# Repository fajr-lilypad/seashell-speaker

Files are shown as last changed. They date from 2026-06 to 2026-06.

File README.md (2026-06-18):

# Seashell Speaker!

A bluetooth speaker that automatically plays when tilted, encased in a seashell case!

  

I came up with this idea when I was thinking about how to expand my audio projects. This was created for hackclub's fallout program, and after first creating an mp3 player, I though the next step would be to make something that could use bluetooth, and then I took it to the next level by making it tilt activated! By coincidence, this is my second ocean-related project, lol. The design was inspired by the story we all know about hearing the ocean come from a shell, and partly inspired by the purple magic conch shell from spongebob, lol.



# Cad Screenshots

<table>
   <tr>
      <td>
   
</td>
      <td>
   
      </td>
   </tr>
</table>

<table>
  <tr>
    <td>
    
    </td>
    <td>
    
    </td>
    <td>
      
    </td>
  </tr>
</table>

Cad Notes:
- Okay, so CAD took a WHILE. Creating such an organic shape was difficult, so ended up relying on the revolve, sweep, and coil tools. Since there arent any tutorials online for creating this type of shell in Fusion either, I had to experiment with blender along with borrowing pieces of 3d models online. Once I had a shape i was happy with, I turned it into a case by splitting it in half, adding holes for magnets, and enclosure for the speaker standoffs for the pcb, and holes for the speaker wires.
- The case itself is pretty easy to use, and I'm happy with how it turned out. If I could go back and change anything, I'd definetly check before hand that my case and pcb were compatible. Orginally, I had planned to tuck my pcb away in the lip/opening of the shell. However, that would be pretty mush impossible without making a HUGE shell case, so I had to basically do a whole redesign of the pcb and case.

# PCB Screenshots

<table>
  <tr>
    <td>
    
    </td>
    <td>
    
    </td>
    <td>
      
    </td>
  </tr>
</table>

  PCB Notes:
   - For the PCB, I did have to go thorugh a few versions. I mostly focused on creating super compact board without hindering the esp32's antenna, which wasn't too bad. However, my first designs were too big too fit in the case, so I had to go back to the drawing board, where I decided to make a round pcb that would sit between the top and bottom halves of the shell.
   - This pcb includes a tilt sensor, charging module, switch, esp32, speaker output headers, and more (see bom)

# Schematic Screenshot
 
 

 # Zine !!



 # BOM

 | Item                 | Purpose                       | #        | Cost   | Supplier           | Link                                                                                                                                                                                                                                                                                                                                                                                                                                                                                                                                                                                                                                                                                                                                                                                                                                                                                                                                       |
|----------------------|-------------------------------|----------|--------|--------------------|--------------------------------------------------------------------------------------------------------------------------------------------------------------------------------------------------------------------------------------------------------------------------------------------------------------------------------------------------------------------------------------------------------------------------------------------------------------------------------------------------------------------------------------------------------------------------------------------------------------------------------------------------------------------------------------------------------------------------------------------------------------------------------------------------------------------------------------------------------------------------------------------------------------------------------------------|
| SW-520D              | Sensor                        | 1        | $1.13  | Aliexpress         | https://www.aliexpress.us/item/3256805875302445.html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                                                                                                                                                                |
| ESP32                | Microcontroller               | 1        | $3.13  | Aliexpress         | https://www.aliexpress.us/item/3256807714347051.html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           |
| MAX98357A            | Amplifier                     | 1        | $1.78  | Aliexpress         | https://www.aliexpress.us/item/3256805196806369.html?gatewayAdapt=glo2usa4itemAdapt                                                                                                                                                                                                                                                                                                                                                                                                                                                                                                                                                                                                                                                                                                                                                                                                                                                        |
| Small Round Magnets  | Enclosure snaps               | 1        | $0.99  | Aliexpress         | https://www.aliexpress.us/item/3256810289404806.html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                                                                                                                                                   |
| 15mm speaker         | Speaker                       | 1        | $2.17  | Aliexpress         | https://www.aliexpress.us/item/3256809180147331.html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 |
| 3.7V Lithium Battery | Battery                       | 1        | $6.67  | Aliexpress         | https://www.aliexpress.us/item/3256803431098963.html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                                                                                                                                                                                                                                                                             |
| TP4056 Module        | Charging Module               | 1        | $0.82  | Aliexpress         | https://www.aliexpress.us/item/3256808777213556.html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                                                                                                                                                                                         |
| AP2112K              | Voltage Regulator             | 1        | $0.26  | Mouser             | https://www.mouser.com/ProductDetail/Diodes-Incorporated/AP2112K-33TRG1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                                                                                                                                                                                                                                                                                                                                                                                                                                                                                                                                                                                                                                                                                                                                                        |
| 3Pin Slide Switch    | Off/On                        | 1        | $0.90  | Aliexpress         | https://www.aliexpress.us/item/2255801021214741.html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                                                                                                                                                   |
| CH340C               | Serial Chip                   | 1        | $0.94  | Aliexpress         | https://www.aliexpress.us/item/3256809981619787.html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                                                                                                                                                   |
| JST 2 Pin Connector  | battery input, speaker output | 2        | $1.97  | Aliexpress         | https://www.aliexpress.us/item/3256808498055527.html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                                                                                                                                                    |
| USB C Receptacle     | Data Input                    | 1        | $2.02  | Aliexpress         | https://www.aliexpress.us/item/3256809263109556.html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                                                                                                                                                               |
| WS2812B              | LED                           | 2        | $0.20  | Ebee               | https://www.ebee.com/product-detail/worldsemi-ws2812b-v5-w_617514.html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                                                                                                                                                                                                                                                                                                                                                                                                                                                                                                                                                                                                                                                                                |
| 74ACHCT125           | Quad Level Shifter            | 1        | $1.50  | Adafruit           | https://www.adafruit.com/product/1787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                                                                                                                                                                                                                                                                                                                                                                                                                                                                                                                                                                                                                                                                                                                  |
| 10uF C               | Capacitor                     | 3        | $0.40  | Digikey            | https://www.digikey.com/en/products/detail/kyocera-avx/REA0511100M025K/20096372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                                                                                                                                                                                                                                                                                                                                                                                                                                                                                                                                                                                                                                                          |
| 0.1uF C              | Capacitor                     | 5        | $0.32  | Sparkfun           | https://www.sparkfun.com/capacitor-ceramic-0-1uf.html                                                                                                                                                                                                                                                                                                                                                                                                                                                                                                                                                                                                                                                                                                                                                                                                                                                                                      |
| 5.1K R               | Resistor                      | 2        | $0.08  | Electronix Express | https://www.elexp.com/products/130155-1kres-1-watt-5-5-1-k-ohm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                                                                                                                                                                                                                                                                                                                                                                                                                                                                                                                                                                                                                                                               |
| 330 R                | Resistor                      | 1        | $0.15  | Newark             | https://www.newark.com/multicomp-pro/mccfr01sj0331a10/carbon-film-resistor-330-ohm-1w/dp/59K8549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|pcrid||plid||kword||match|e|slid||product|59K8549|pgrid|1231453304461926|ptaid|pla-4580565455222458|&msclkid=0d6d44d2aa3b1af1a3812efec2f401f3                                                                                                                                                                                                                                                                                                                                                                                                                                                                                                                                                                                                                                                     |
| 10K R                | Resistor                      | 3        | $0.19  | Newark             | https://www.newark.com/multicomp-pro/mf12-10k/res-10k-125mw-axial-metal-film/dp/38K5401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                                                                                                                                                                                                                                                                                                                                                                                                                                                                                                                                                                                                                   |
| 100K R               | Resistor                      | 1        | $0.24  | Newark             | https://www.newark.com/ohmite/mox70031003bye/resistor-metal-film-100k-0-25w/dp/49AJ2825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|pcrid||plid||kword||match|e|slid||product|49AJ2825|pgrid|1231453304461926|ptaid|pla-4580565455222458|&msclkid=8346f4e1e0f2133c086d9ecd89969e59                                                                                                                                                                                                                                                                                                                                                                                                                                                                                                                                                                                                                                                             |
| S8050                | Transistor                    | 1        | $0.84  | Aliexpress         | https://www.aliexpress.us/item/3256808228534673.html?src=google&gatewayAdapt=glo2usa                                                                                                                                                                                                                                                                                                                                                                                                                                                                                                                                                                                                                                                                                                                                                                                                                                                       |
| BC847                | Transistor                    | 1        | $0.19  | Mouser             | https://www.mouser.com/ProductDetail/Nexperia/BC847235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                                                                                                                                                                                                                                                                                                                                                                                                                                                                                                                                                                        |
| PCB Order            | PCB                           | 1        | $2.10  | JLCPCB             |                                                                                                                                                                                                                                                                                                                                                                                                                                                                                                                                                                                                                                                                                                                                                                                                                                                                                                                                            |
|                      |                               | Subtotal | $28.99 |                    |                                                                                                                                                                                                                                                                                                                                                                                                                                                                                                                                                                                                                                                                                                                                                                                                                                                                                                                                            |

## Firmware

Unlike my previous audio projects, instead of using a micro sd card storing songs played by a df player, I used bluetooth connection via an esp32 and a BluetoothA2DPSink library I found from user pschatzmann. The code is fairly simple, and checks the tilt sensor in the background periodically, intercepting when a tilt is detected to pause/play audio.

## Build Guide
1. 3D print Case, ensure that standoffs and holes are secure and remove all supports.
2. Collect all electronic parts and perform breadboard testing before soldering onto custom pcb
3. Flash fimrware with new pcb, connect to bluetooth so you see "Bluetooth Speaker Audio Ready to Pair!" message printed.
4. Test out tilt puasing/playing audio
5. Mount fully charged pcb onto built in standoffs in top of case.
6. Place speaker in enclosure, thread wires through holes and plug into headers in pcb.
7. Place magnets in small holes in shell case, snap case shut.

## Notes and Acknowledgements
- Thank you to *hackclub* and the *fallout* team for this oppurtunity and for making this project possible!

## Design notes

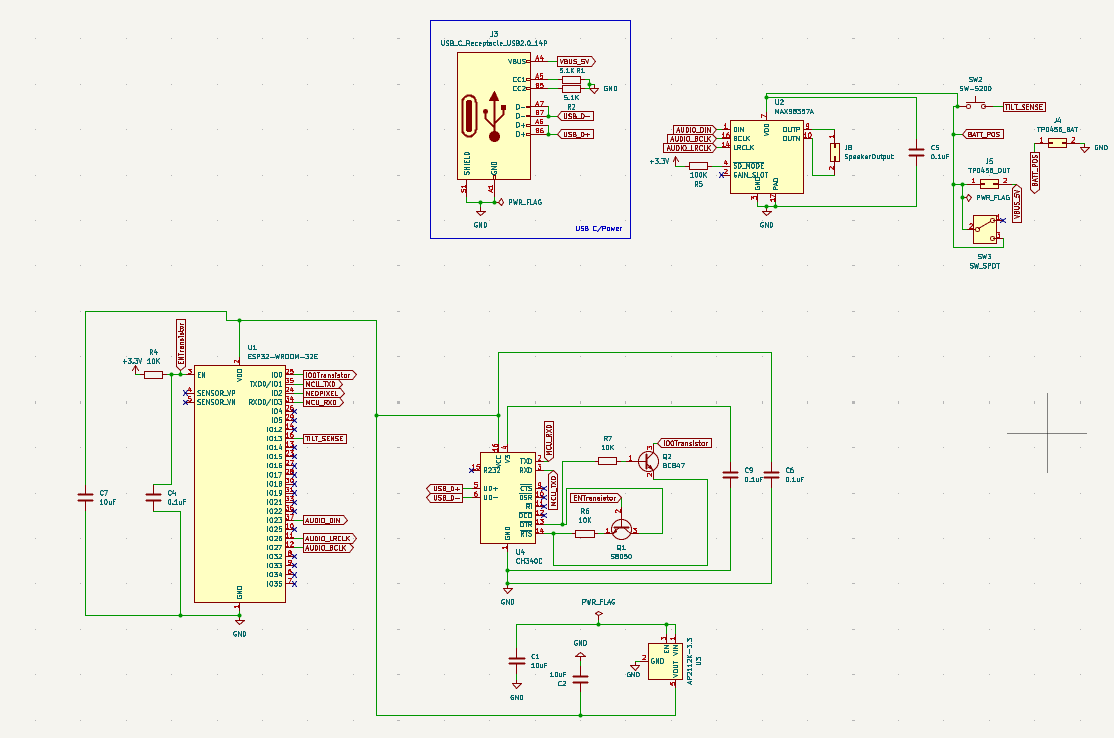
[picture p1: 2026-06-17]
Schematic/Schematic.png

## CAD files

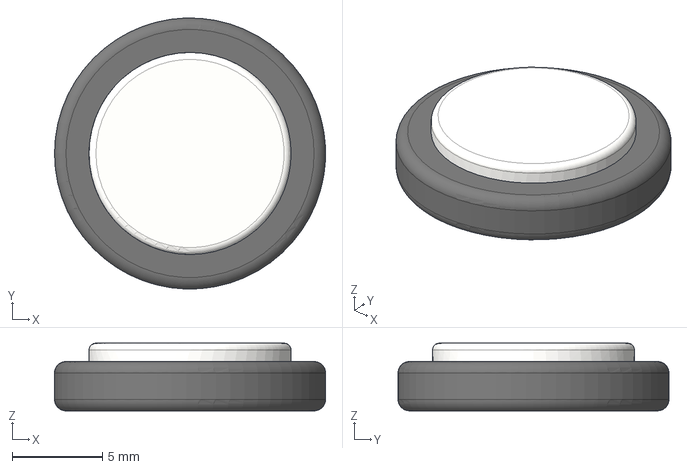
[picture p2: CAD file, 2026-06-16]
CAD/PCB Files/Electronics/15mm speaker.step
15.0 x 15.0 x 3.74 mm

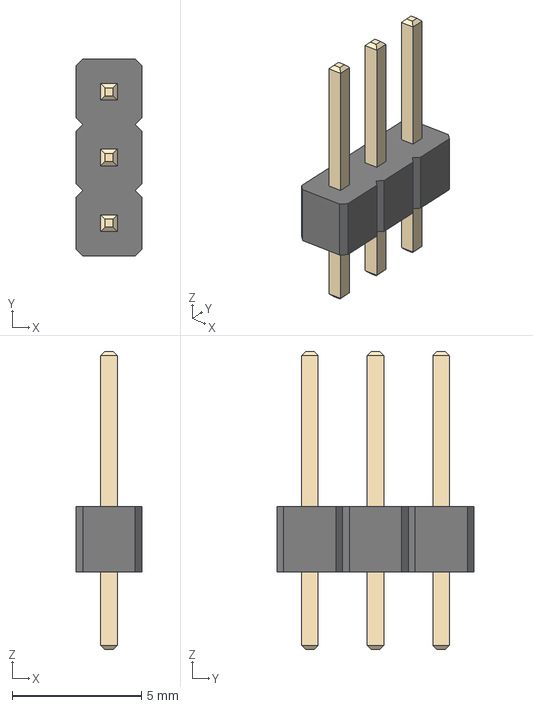
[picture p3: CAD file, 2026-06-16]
CAD/PCB Files/Electronics/PinHeader_1x03_P2.54mm_Vertical (for speaker output).step
2.54 x 7.62 x 11.5 mm

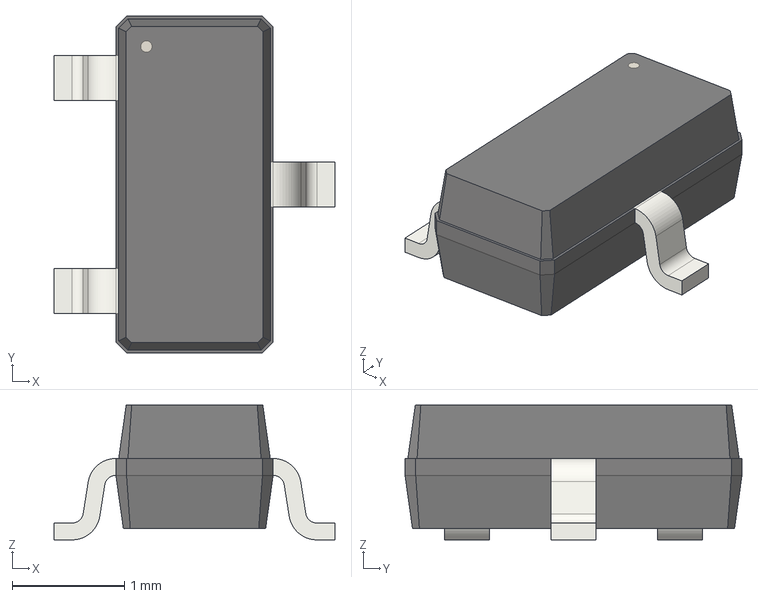
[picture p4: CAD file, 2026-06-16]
CAD/PCB Files/Electronics/SOT-23.step
2.50 x 3.00 x 1.20 mm

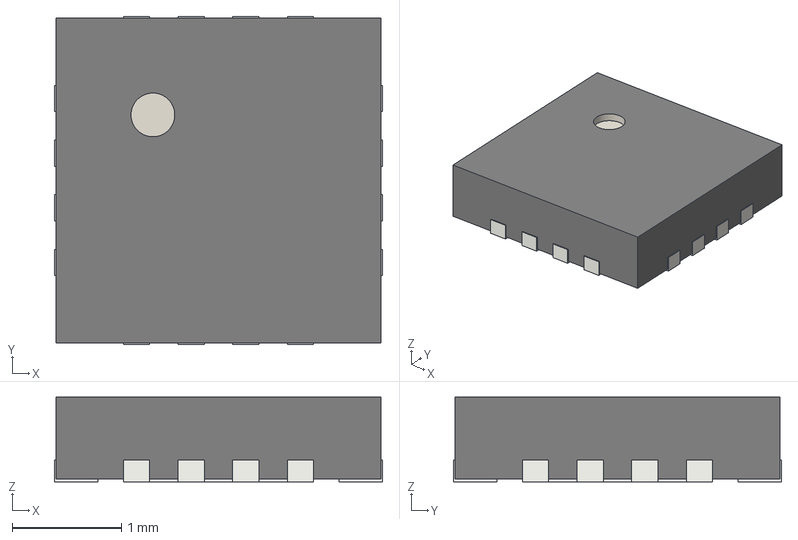
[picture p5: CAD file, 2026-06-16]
CAD/PCB Files/Electronics/TQFN-16-1EP_3x3mm_P0.5mm_EP1.6x1.6mm.step
3.00 x 3.00 x 0.775 mm

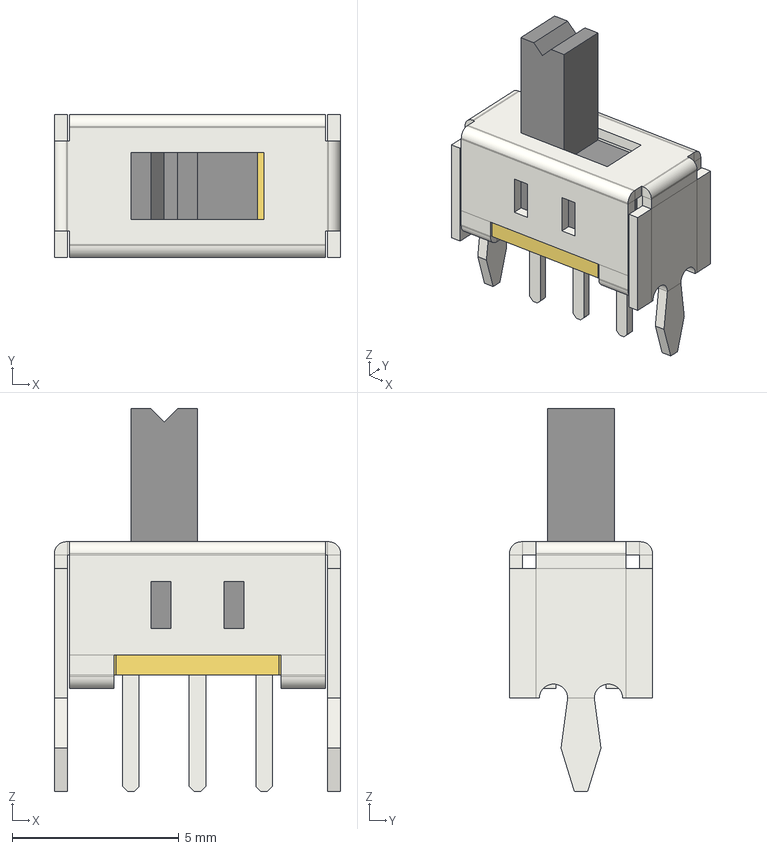
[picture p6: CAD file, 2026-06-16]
CAD/PCB Files/Electronics/SW_Slide_SPDT_Straight_CK_OS102011MS2Q.step
8.60 x 4.30 x 11.5 mm

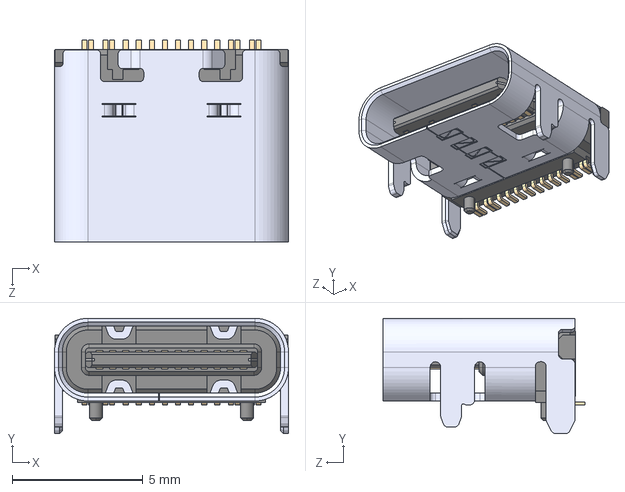
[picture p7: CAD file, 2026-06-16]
CAD/PCB Files/Electronics/USB4105GFA--3DModel-STEP-510211.STEP
8.94 x 4.41 x 7.71 mm

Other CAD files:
CAD/PCB Files/pcb (no components).step
CAD/Full Assembly.f3z

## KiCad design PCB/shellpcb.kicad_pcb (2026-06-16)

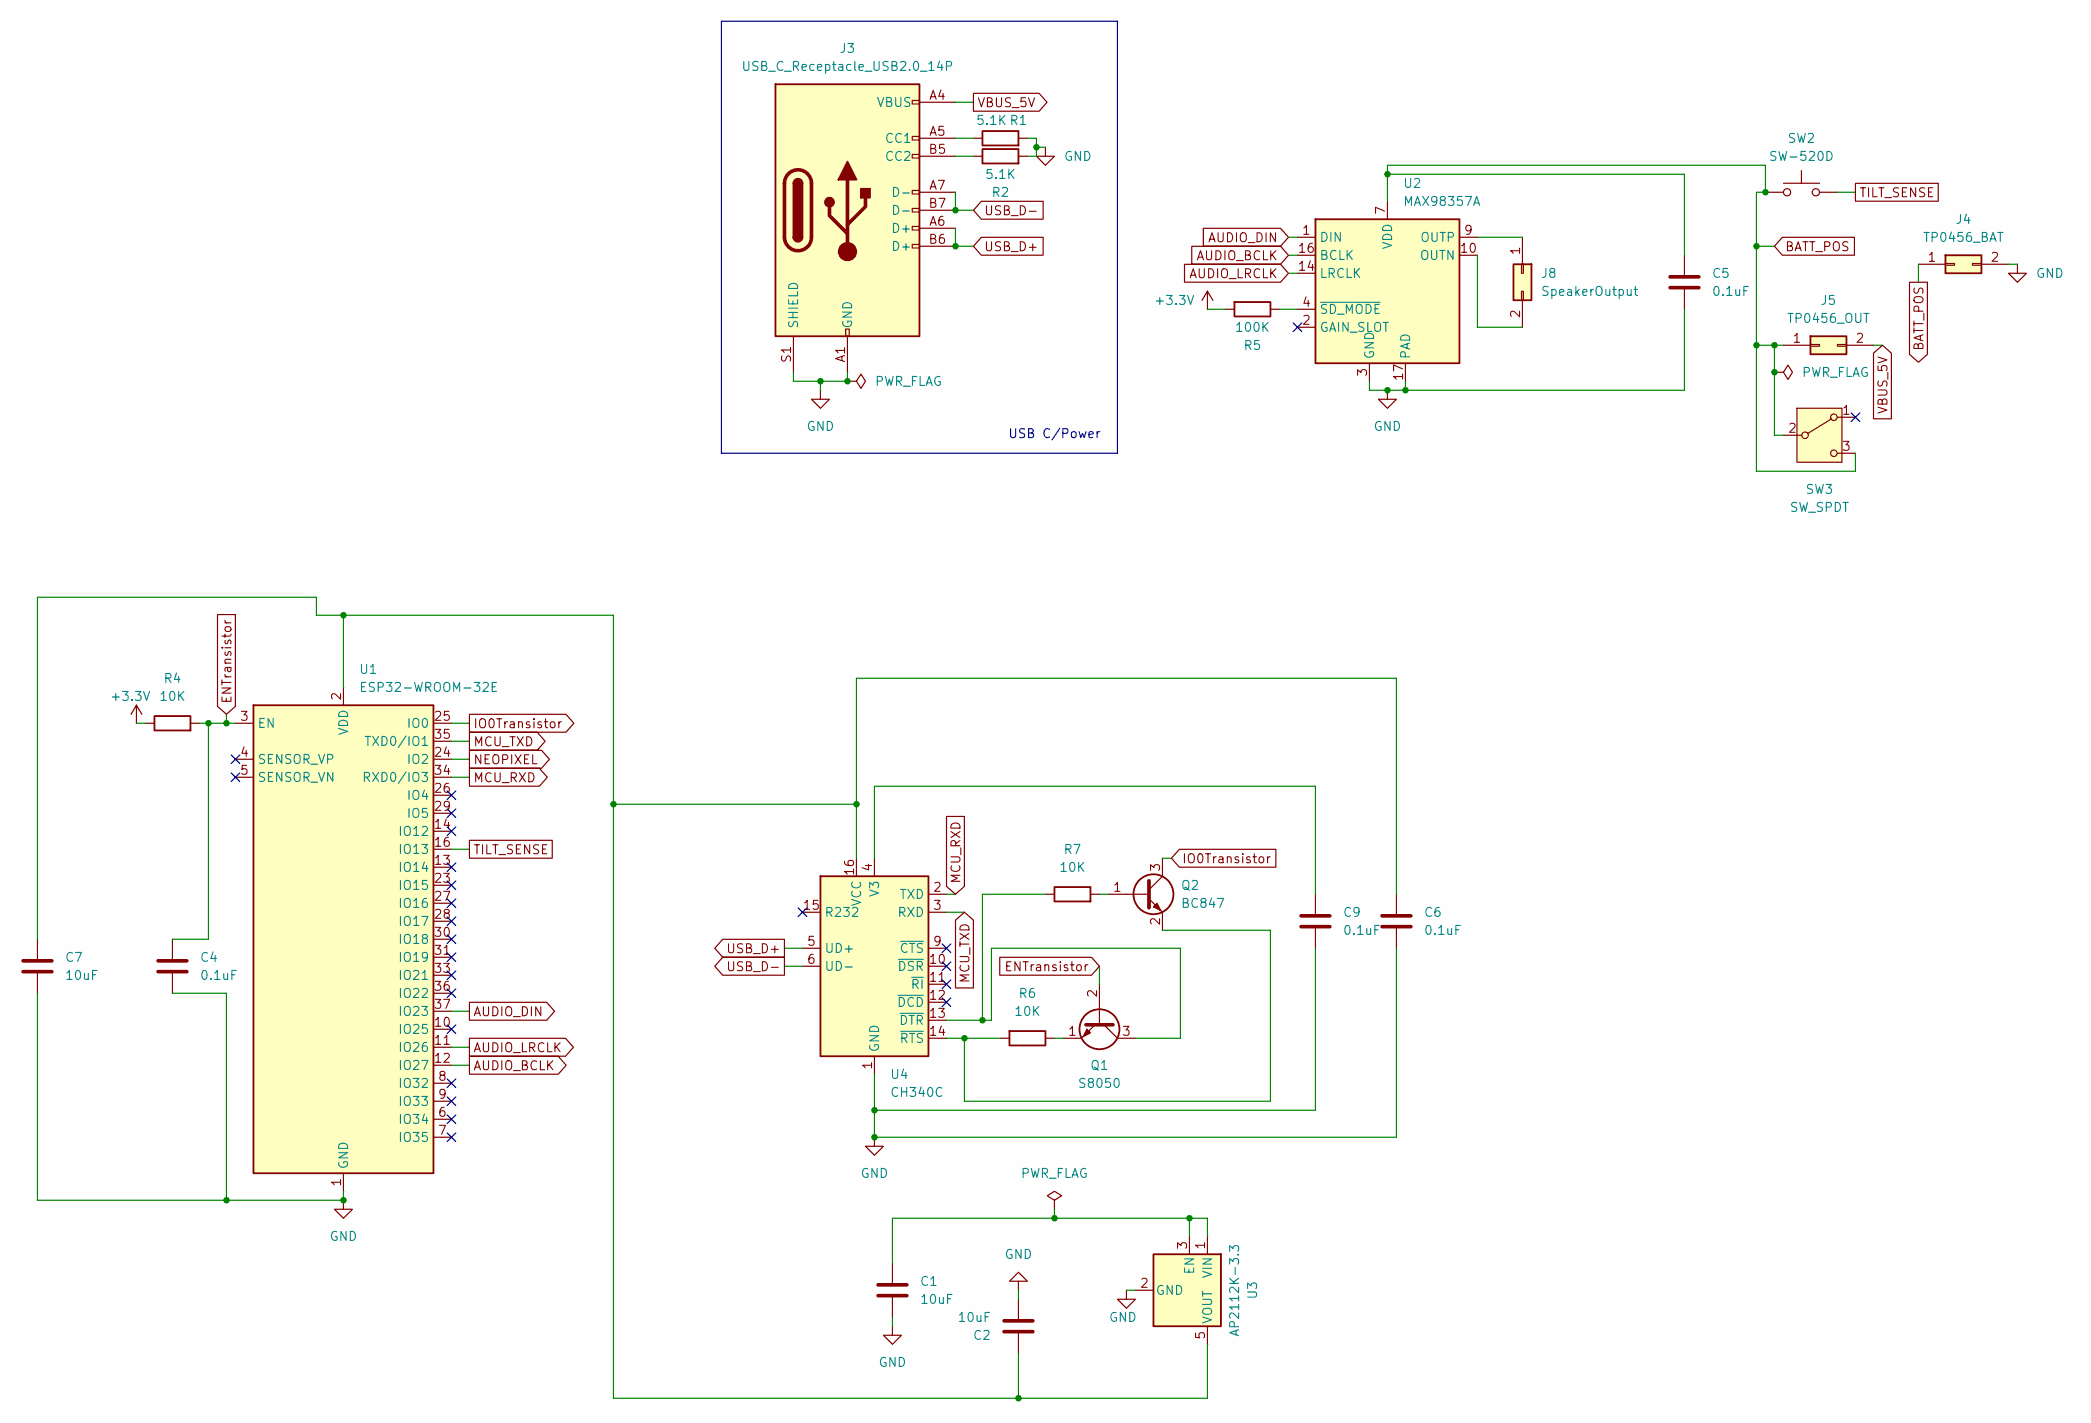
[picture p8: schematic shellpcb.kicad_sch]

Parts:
C1, C2, C7: 10uF; C_0603_1608Metric
C4, C5, C6, C9: 0.1uF; C_0402_1005Metric
J3: USB_C_Receptacle_USB2.0_14P; USB_C_Receptacle_HRO_TYPE-C-31-M-12
J4: TP0456_BAT; Batside
J5: TP0456_OUT; Outside
J8: SpeakerOutput; PinHeader_1x03_P2.54mm_Vertical
Q1: S8050; TO-92_Inline
Q2: BC847; SOT-23
R1, R2: 5.1K; R_0402_1005Metric
R4, R6, R7: 10K; R_0402_1005Metric
R5: 100K; R_0402_1005Metric
SW2: SW-520D; PinHeader_1x02_P2.54mm_Vertical
SW3: SW_SPDT; SW_Slide_SPDT_Straight_CK_OS102011MS2Q
U1: ESP32-WROOM-32E; ESP32-WROOM-32D
U2: MAX98357A; TQFN-16-1EP_3x3mm_P0.5mm_EP1.6x1.6mm
U3: AP2112K-3.3; SOT-23-5
U4: CH340C; SOIC-16_3.9x9.9mm_P1.27mm

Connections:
+3.3V: R4.1, R5.2
AUDIO_BCLK: U1.12 (IO27), U2.16 (BCLK)
AUDIO_DIN: U1.37 (IO23), U2.1 (DIN)
AUDIO_LRCLK: U1.11 (IO26), U2.14 (LRCLK)
BATT_POS: C5.1, J4.1, J5.1, SW2.1, SW3.2 (B), SW3.3 (C), U2.7 (VDD), U2.8 (VDD)
ENTransistor: C4.1, Q1.2 (B), R4.2, U1.3 (EN)
GND: C1.2, C2.1, C4.2, C5.2, C6.2, C7.2, C9.2, J3.A1 (GND), J3.A12 (GND), J3.B1 (GND), J3.B12 (GND), J3.S1 (SHIELD), J4.2, R1.2, R2.2, U1.1 (GND), U1.15 (GND), U1.38 (GND), U1.39 (GND), U2.3 (GND), U2.11 (GND), U2.15 (GND), U2.17 (PAD), U3.2 (GND), U4.1 (GND)
IO0Transistor: Q2.3 (C), U1.25 (IO0)
MCU_RXD: U1.34 (RXD0/IO3), U4.2 (TXD)
MCU_TXD: U1.35 (TXD0/IO1), U4.3 (RXD)
NEOPIXEL: U1.24 (IO2)
unnamed: J3.A5 (CC1), R1.1
unnamed: J3.B5 (CC2), R2.1
unnamed: J8.1, U2.9 (OUTP)
unnamed: J8.2, U2.10 (OUTN)
unnamed: Q1.3 (C), R7.1, U4.13 (~DTR)
unnamed: Q1.1 (E), R6.1
unnamed: Q2.1 (B), R7.2
unnamed: Q2.2 (E), R6.2, U4.14 (~RTS)
unnamed: C2.2, C6.1, C7.1, U1.2 (VDD), U3.5 (VOUT), U4.16 (VCC)
unnamed: R5.1, U2.4 (~SD_MODE)
unnamed: C1.1, U3.1 (VIN), U3.3 (EN)
unnamed: C9.1, U4.4 (V3)
TILT_SENSE: SW2.2, U1.16 (IO13)
USB_D+: J3.A6 (D+), J3.B6 (D+), U4.5 (UD+)
USB_D-: J3.A7 (D-), J3.B7 (D-), U4.6 (UD-)
VBUS_5V: J3.A4 (VBUS), J3.A9 (VBUS), J3.B4 (VBUS), J3.B9 (VBUS), J5.2

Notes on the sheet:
USB C/Power

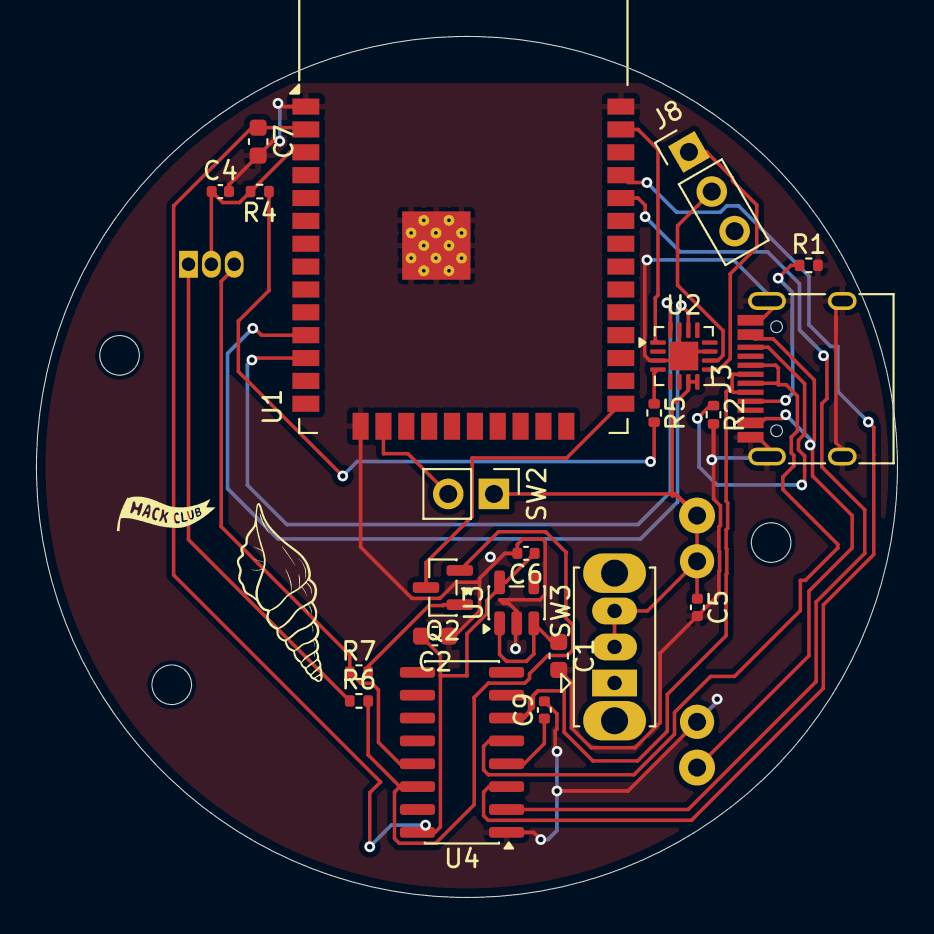
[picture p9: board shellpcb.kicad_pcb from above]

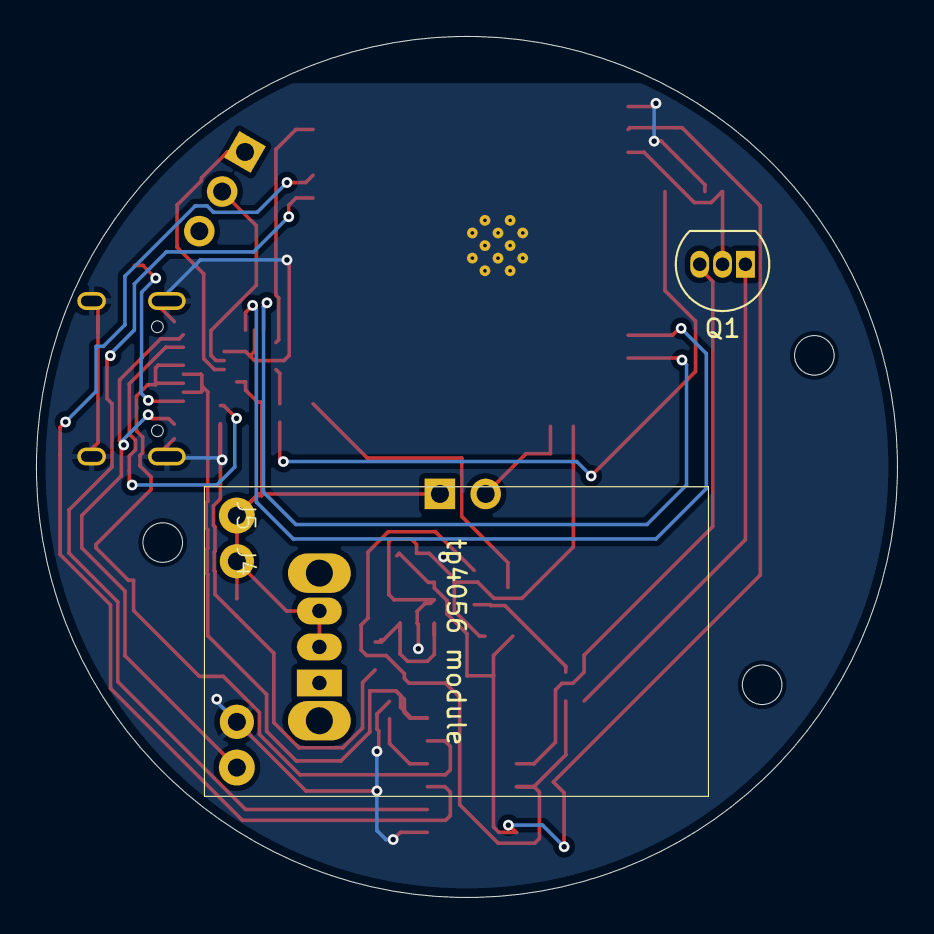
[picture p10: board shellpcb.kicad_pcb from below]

Board: 2 copper layers, 47.8 x 47.8 mm, 25 parts (3 on the bottom side), 26 nets.

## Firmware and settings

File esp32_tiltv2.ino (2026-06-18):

#include "ESP_I2S.h"         // Modern ESP32 Core v3 Audio Driver
#include "BluetoothA2DPSink.h" // Library to turn ESP32 into a BT Speaker

// Define your exact schematic pins for the MAX98357A Amp
#define I2S_BCLK          26  // AUDIO_BCLK on IO26
#define I2S_LRCK          27  // AUDIO_LRCLK on IO27
#define I2S_DOUT          25  // AUDIO_DIN on IO25

#define TILT_SWITCH_PIN   12  // SW2 connected to IO12

// Initialize the modern I2S audio driver instance
I2SClass i2s;

// Pass the I2S driver instance into the Bluetooth sink constructor
BluetoothA2DPSink a2dp_sink(i2s);

void setup() {
  Serial.begin(115200);

  // 1. Configure the Tilt Switch
  pinMode(TILT_SWITCH_PIN, INPUT_PULLUP);

  // 2. Configure the I2S hardware pin connections using the modern method
  i2s.setPins(I2S_BCLK, I2S_LRCK, I2S_DOUT, -1, -1); // (BCLK, WS/LRCK, DOUT, DIN, MCLK)

  // 3. Start the Bluetooth Speaker broadcast name!
  // This is the name you will see on your phone's Bluetooth settings screen.
  a2dp_sink.start("My Custom Shell");
  
  Serial.println("Bluetooth Speaker Audio Ready to Pair!");
}

void loop() {
  int switchState = digitalRead(TILT_SWITCH_PIN);

  if (switchState == LOW) {
    // If the shell is level, do nothing and let the music play normally
  } else {
    Serial.println("Shell Tilted! Pausing Spotify...");
    // The instant the shell is tilted, force your phone to PAUSE Spotify!
    if (a2dp_sink.is_connected()) {
        a2dp_sink.pause(); 
    }
  }

  delay(300); // Check the tilt switch a few times a second
}

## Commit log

2026-06-16 Rename pcb (no components).step to CAD/PCB Files/pcb (no components).step
    [pcb (no components).step]
2026-06-16 Rename CAD/PCB Files/ESP32-C3-DEVKITM-1--3DModel-STEP-56544.STEP to CAD/PCB Files/Electronics/ESP32-C3-DEVKITM-1--3DModel-STEP-56544.STEP
    [ESP32-C3-DEVKITM-1--3DModel-STEP-56544.STEP]
2026-06-16 Rename CAD/Shell Case Top.step to CAD/Case/Shell Case Top.step
    [Shell Case Top.step]
2026-06-16 Rename CAD/Shell Case bottom.step to CAD/Case/Shell Case bottom.step
    [Shell Case bottom.step]
2026-06-17 Create Full Assembly.f3z
2026-06-17 Rename Full Assembly.f3z to CAD/Full Assembly.f3z
    [Full Assembly.f3z]
2026-06-17 Rename Screenshot 2026-06-17 150042.png to Schematic/Screenshot 2026-06-17 150042.png
2026-06-17 Rename Screenshot 2026-06-17 150042.png to Schematic.png
